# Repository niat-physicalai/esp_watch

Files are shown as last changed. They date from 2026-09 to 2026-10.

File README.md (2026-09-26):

# ESP Watch

A custom ESP32-C3-based wearable device that combines a small OLED display, motion sensing, heart-rate sensing,
Wi-Fi/BLE connectivity, and a LiPo battery into a compact wrist-worn platform.

The project covers the complete product-development workflow — from breadboard prototyping and firmware development
to schematic capture, custom PCB design, fabrication, and enclosure CAD.

## Features

* **Seeed XIAO ESP32-C3**
* **0.96" 128×64 SSD1306 OLED**
* **MPU-6050** 6-axis IMU
* **MAX30102** heart-rate / SpO₂ sensor
* 2 user buttons
* LiPo battery operation
* Wi-Fi / Bluetooth Low Energy
* Custom 2-layer carrier PCB
* 3D-printed enclosure

---

## Hardware

| Component | Details |
| --- | --- |
| MCU | XIAO ESP32-C3 |
| Display | SSD1306 OLED, 128×64 |
| IMU | MPU-6050 |
| Heart-rate sensor | MAX30102 |
| Communication | Wi-Fi + BLE |
| Power | LiPo |
| PCB | Custom 38 × 38 mm, 2-layer |

## System Architecture
                         LiPo Battery
                              │
                       Optional Switch
                              │
                       XIAO BAT+ / BAT-
                              │
                    ┌─────────┴─────────┐
                    │                   │
                 XIAO ESP32-C3       Charger
                    │
                  3.3 V
                    │
          ┌─────────┼──────────┐
          │         │          │
       SSD1306   MPU-6050   MAX30102
       OLED       IMU       HR / SpO₂
       0x3C       0x68         0x57
          │         │          │
          └─────────┴──────────┘
                 I²C Bus
             SDA = GPIO6
             SCL = GPIO7

       GPIO10 ── Next Button
       GPIO3 ── Previous Button

### Pinout

| XIAO Pin | Function |
| --- | --- |
| D4 / GPIO6 | I²C SDA |
| D5 / GPIO7 | I²C SCL |
| D10 / GPIO10 | Next button |
| D1 / GPIO3 | Previous button |

The OLED, MPU-6050 and MAX30102 share the I²C bus. No interrupt pins are used for the MPU-6050 or MAX30102.

### Battery

The reference design currently treats the battery as a placeholder. The documented placeholder is:

Capacity: 400 mAh
Approximate dimensions: 20 × 5 × 13 mm

---

## Breadboard Prototype

The watch electronics were first assembled and tested on a breadboard before moving to the custom PCB.

**Figure 1 — Breadboard prototype**

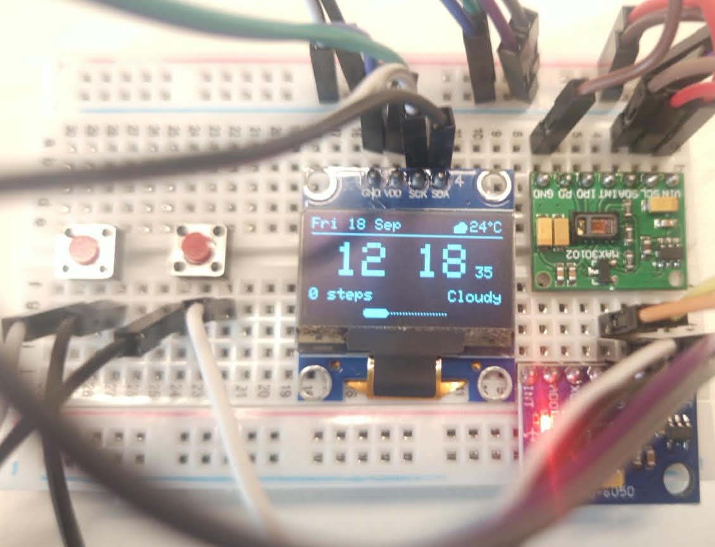
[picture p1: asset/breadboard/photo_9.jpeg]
Breadboard Prototype


*Initial ESP32-C3 smartwatch prototype with the display and sensor modules connected for firmware and hardware testing.*

Additional prototype photos are available in [`asset/breadboard/`](asset/breadboard/).

---

## Circuit Schematic

The final circuit was designed around the XIAO ESP32-C3 with the display and sensors connected through the I²C bus.

**Figure 2 — Circuit schematic**

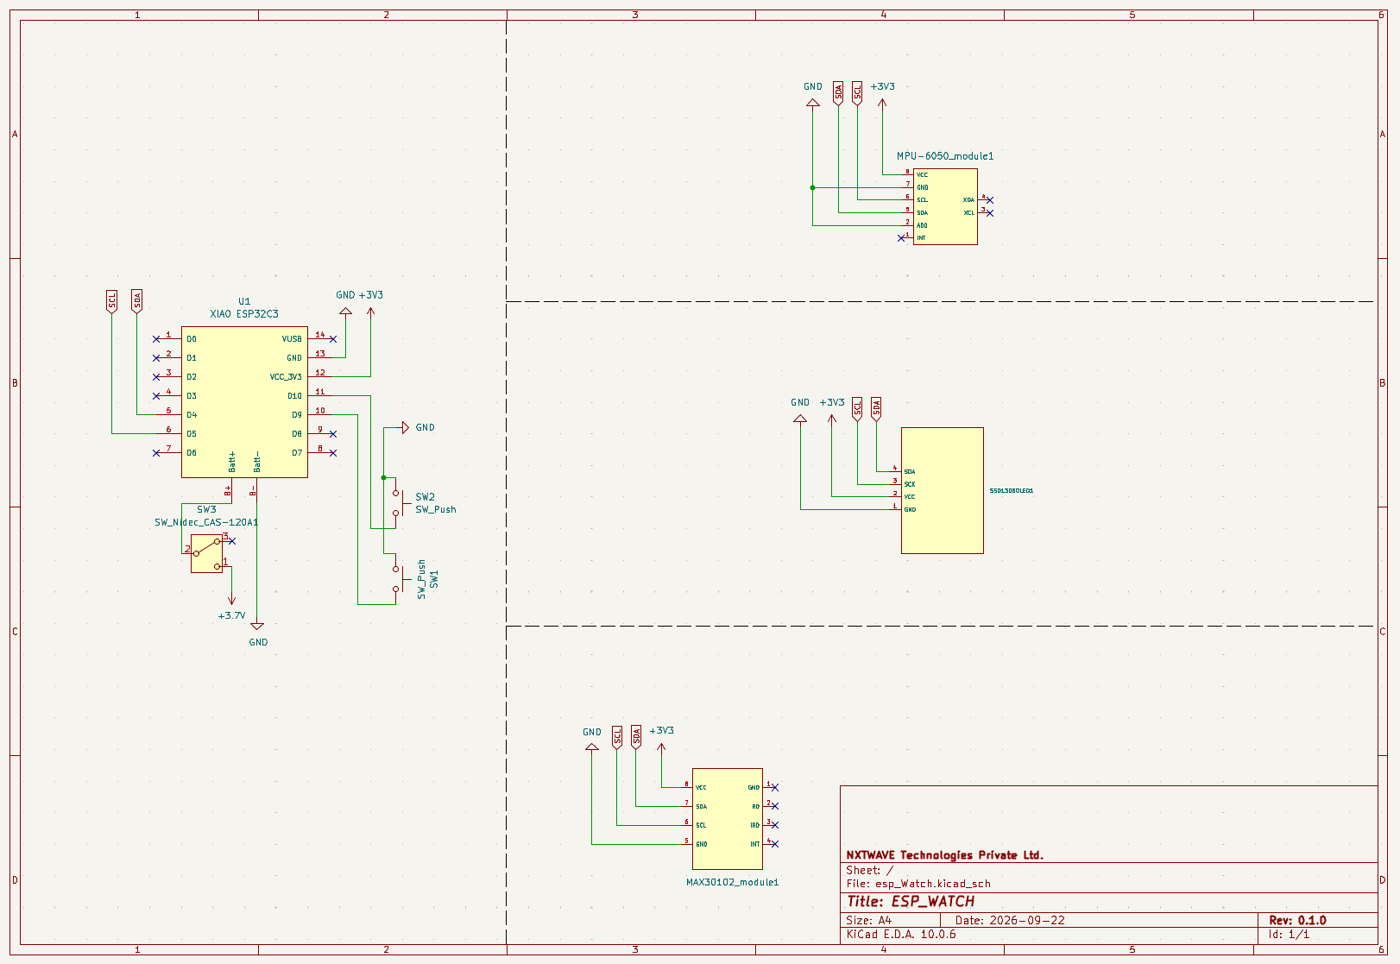
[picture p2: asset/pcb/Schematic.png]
ESP Watch Schematic


*Complete schematic of the ESP Watch carrier board.*

---

## PCB Design

The prototype was converted into a custom 2-layer carrier PCB measuring approximately **38 × 38 mm**.

The custom carrier PCB is:
* 38 × 38 mm
* 2-layer
* Module-based design
* Custom KiCad schematic symbols
* Custom MAX30102 footprint
* Ground pours on both layers
* Hand-assembly oriented

**Figure 3 — PCB top view**

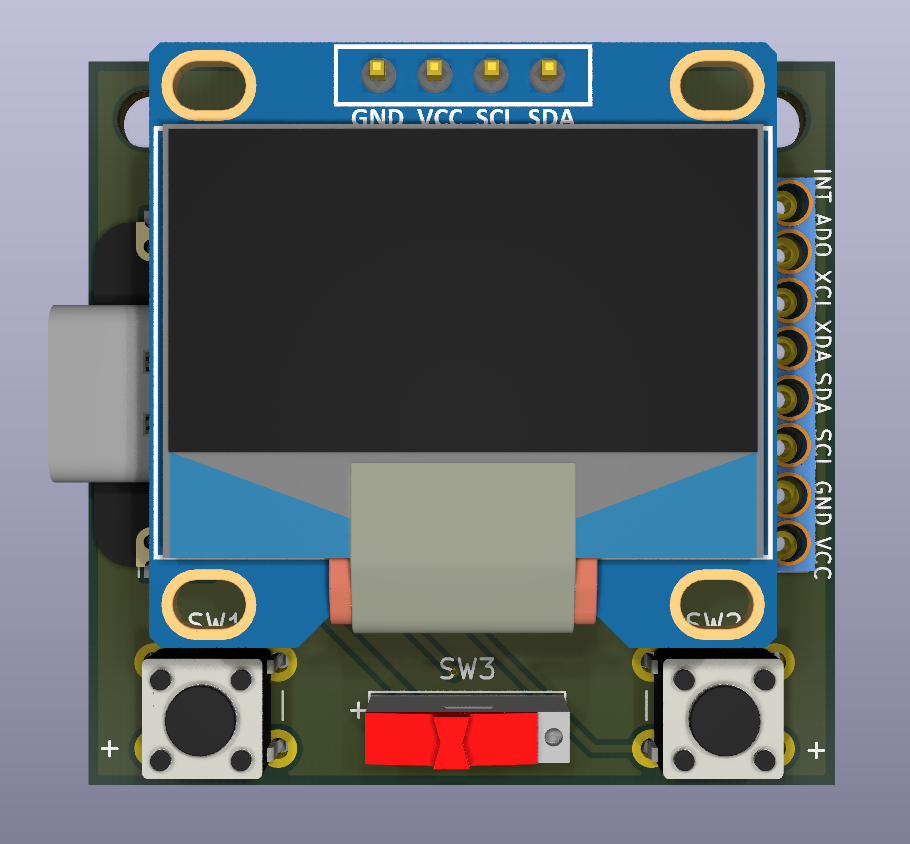
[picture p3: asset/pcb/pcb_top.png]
PCB Top


*Fully rendered top view showing the component placement and routing of the ESP Watch PCB.*

**Figure 4 — PCB front copper**

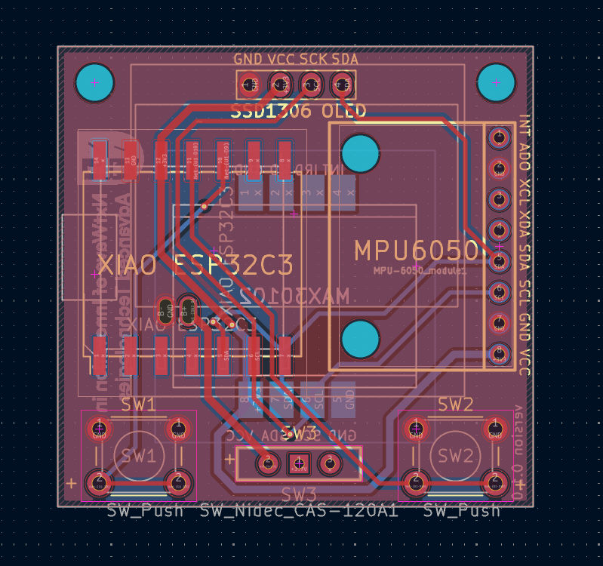
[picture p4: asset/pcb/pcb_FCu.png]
PCB Front Copper


*Front copper layer showing signal and power routing.*

The repository also contains additional PCB views and renders in [`asset/pcb/`](asset/pcb/).

---

## Firmware

Firmware is written in Arduino C++ and can be developed using:

* **Arduino IDE** — `firmware/Arduino-IDE/`
* **PlatformIO** — `firmware/PlatformIO/`

The firmware interfaces with the display and sensors over I²C and handles the watch UI, buttons, motion and heart-rate functionality.

---

## Getting Started
### 1. Clone the repository
```bash
git clone https://github.com/niat-physicalai/esp_watch.git
cd esp_watch
```

### 2. Firmware

Choose one of the supported development environments:

firmware/
├── Arduino-IDE/
└── PlatformIO/

### Arduino IDE

Open:

`firmware/Arduino-IDE/esp_watch/esp_watch.ino`

Select the appropriate ESP32-C3 board configuration and upload the firmware.

### PlatformIO

Open:

`firmware/PlatformIO/esp_watch/`

using VS Code with the PlatformIO extension.

Then build and upload the project.

*Note** Exact board-manager/library versions and firmware configuration requirements should be verified against the current project files before treating them as fixed requirements.

---

## Repository Structure

```text
esp_watch/
├── asset/
│   ├── breadboard/      # Prototype photos
│   └── pcb/             # PCB renders and schematic
│
├── firmware/
│   ├── Arduino-IDE/     # Arduino IDE firmware
│   └── PlatformIO/      # PlatformIO project
│
├── README.md
└── dir.txt
```

---

## Status

* [x] Breadboard prototype
* [x] Firmware
* [x] PCB design
* [ ] PCB fabrication / assembly
* [ ] Enclosure development

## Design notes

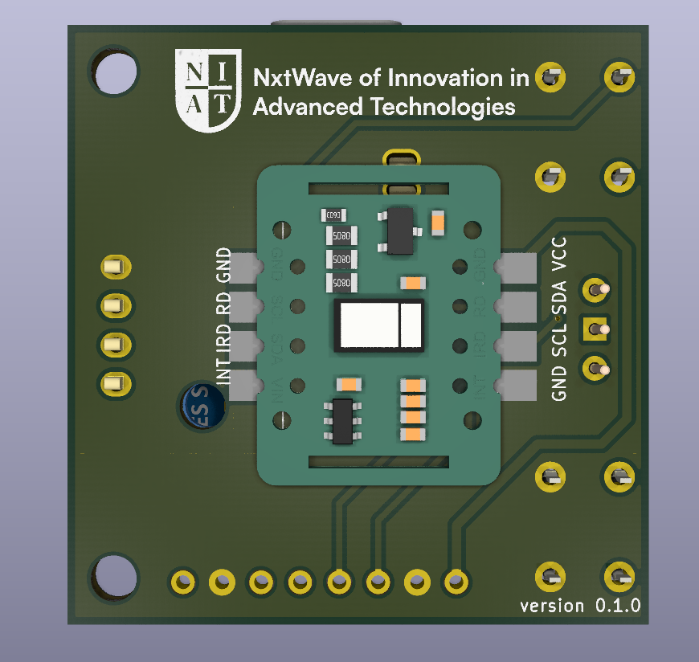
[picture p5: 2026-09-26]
asset/pcb/pcb_back.png

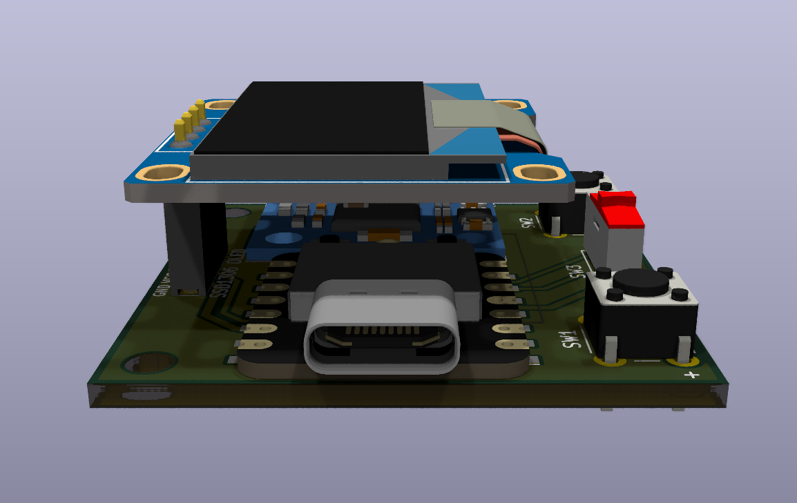
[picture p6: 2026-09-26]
asset/pcb/pcb_side.png

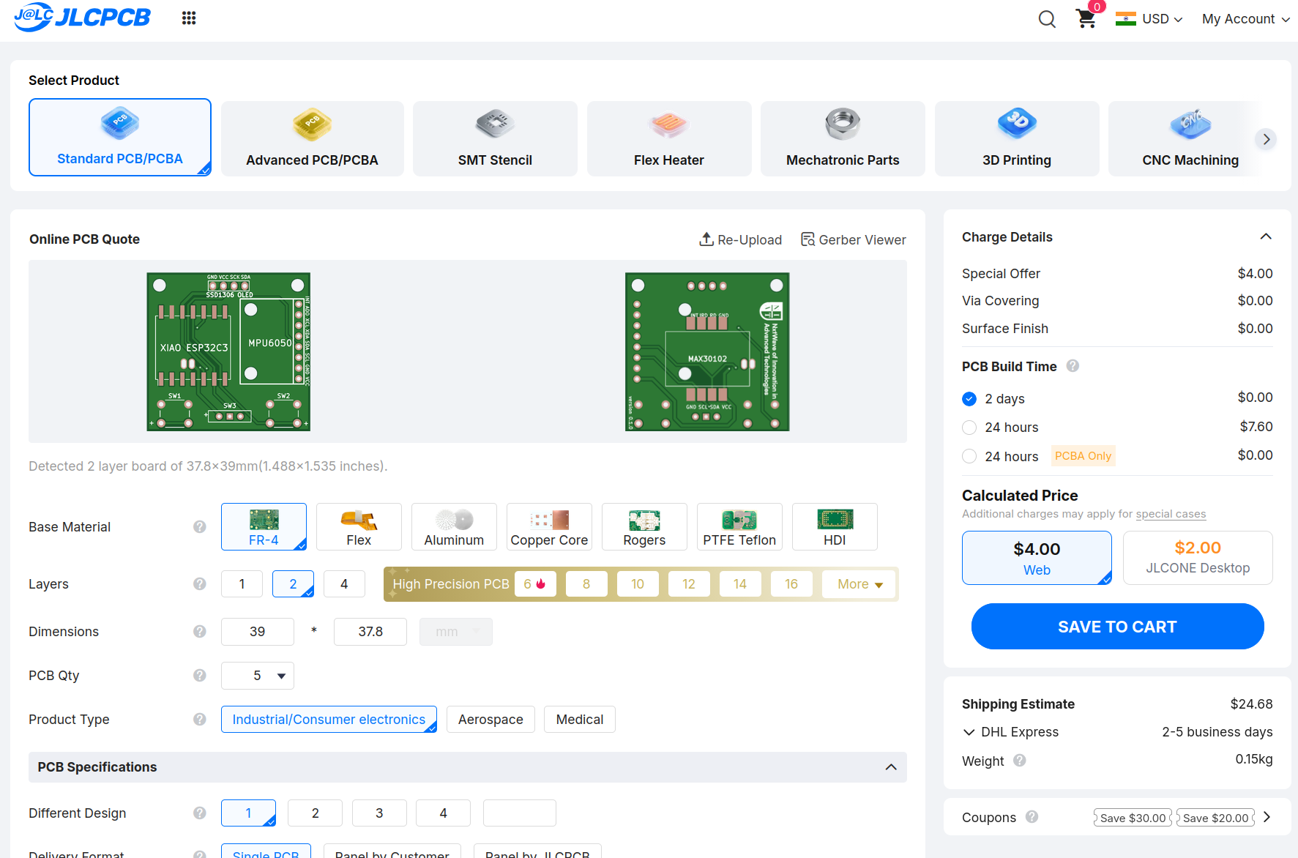
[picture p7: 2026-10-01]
asset/pcb/JLCPCB_quote.png

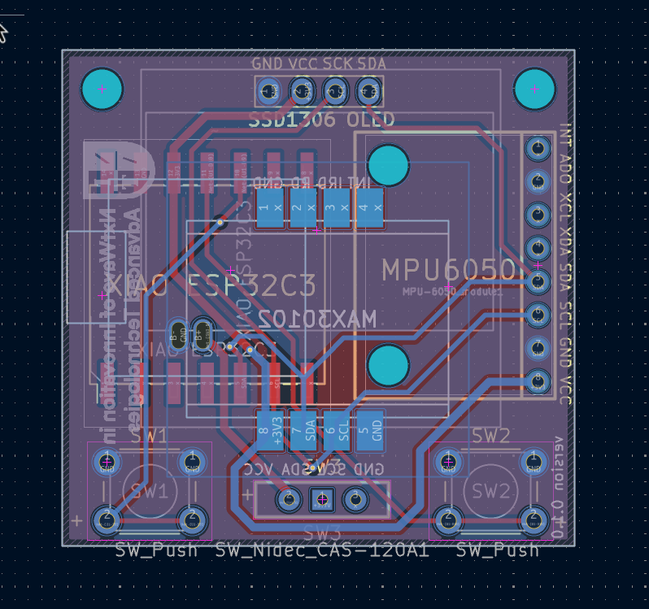
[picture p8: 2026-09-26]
asset/pcb/pcb_BCu.png

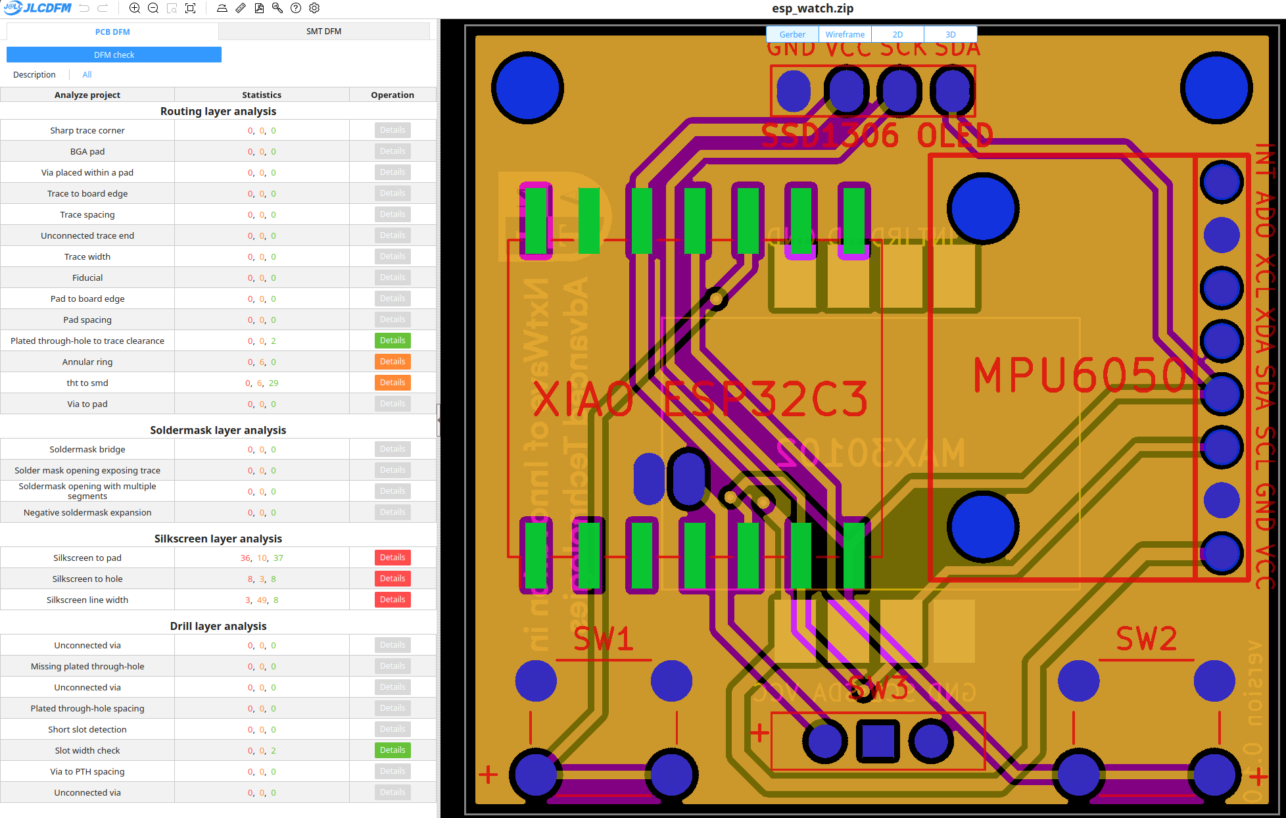
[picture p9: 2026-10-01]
asset/pcb/DFM_check.png

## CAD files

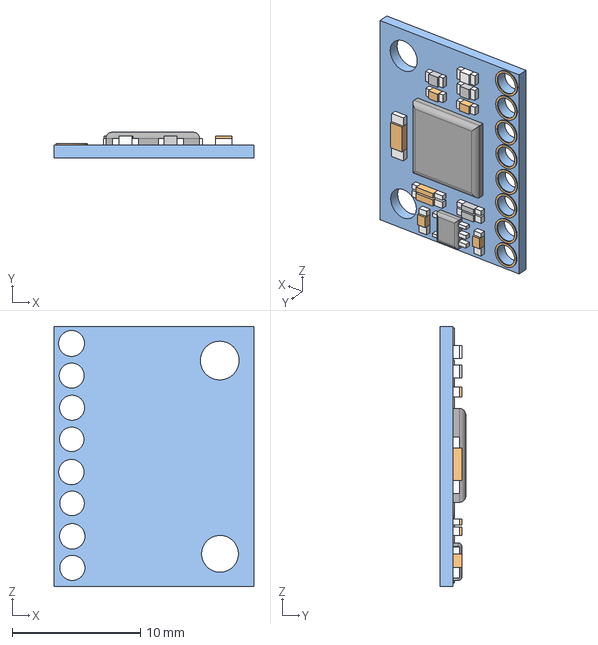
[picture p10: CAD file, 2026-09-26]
pcb/esp_Watch/3d models/MPU6050 v2.step
15.6 x 2.00 x 20.3 mm

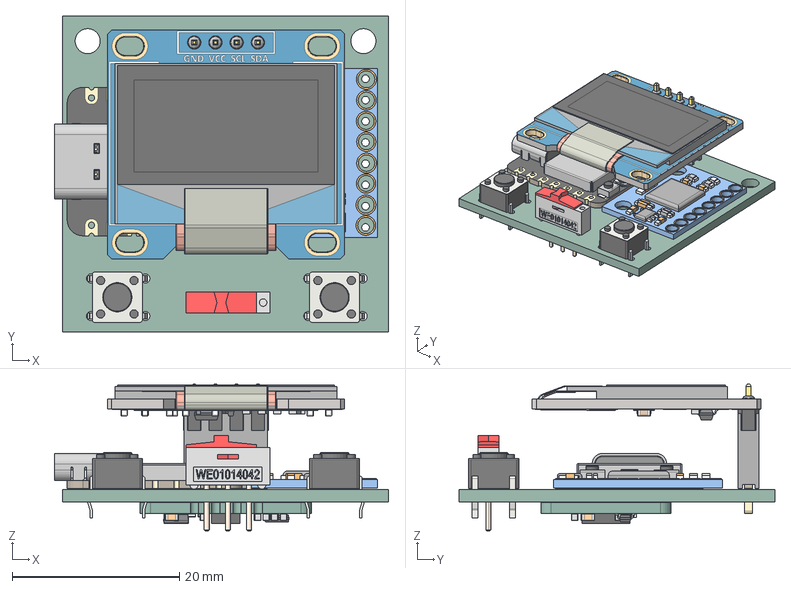
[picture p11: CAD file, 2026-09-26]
pcb/esp_Watch/esp_Watch.step
40.0 x 37.8 x 17.6 mm
662k - XC6206P182MR-G
R SMD 472 x 4
R SMD 914
C SMD 0603 x 8
SOD323F_DIO
Female Pin Header v1
MPU6050 v2
BOSS-EXTRUDE14_8_
BOSS-EXTRUDE7_4_
BOSS-EXTRUDE7_3_
BOSS-EXTRUDE14_4_
BOSS-EXTRUDE14_2_
BOSS-EXTRUDE14_11_
BOSS-EXTRUDE7_7_
BOSS-EXTRUDE14_9_
BOSS-EXTRUDE14_3_
BOSS-EXTRUDE14_7_
MIRROR2
BOSS-EXTRUDE14_5_
BOSS-EXTRUDE14_12_
BOSS-EXTRUDE7_8_
BOSS-EXTRUDE7_1_
BOSS-EXTRUDE14_10_
BOSS-EXTRUDE7_9_
BOSS-EXTRUDE14_6_
BOSS-EXTRUDE14_1_
BOSS-EXTRUDE7_6_
BOSS-EXTRUDE7_2_
CUT-EXTRUDE5
BOSS-EXTRUDE7_5_
U.FL Connector v1
Button (1) x 2
Shield
SW_PUSH_6mm x 2
SOT-23-6 v1
ceramic_cap_0603 v1 x 7
Деталь1 x 4
Деталь2 x 8
SOT23-3 v1
esp_Watch_PCB

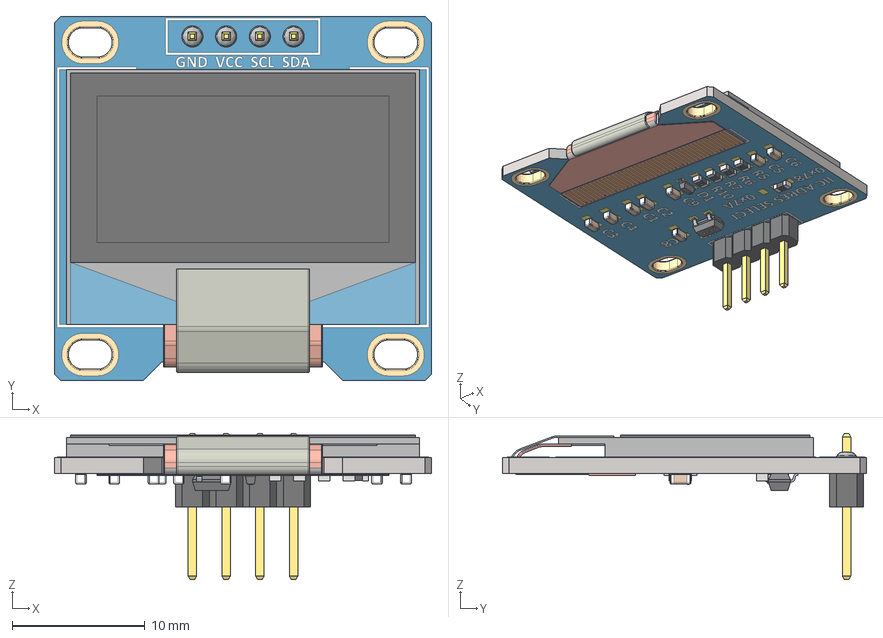
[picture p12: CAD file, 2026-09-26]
pcb/esp_Watch/3d models/Pantalla OLED 0.96'' 128x64.stp
28.4 x 27.4 x 11.0 mm
SOT-23_TOR
RES_CR16_MTK_1 x 4
RES_CR16_MTK
SOD323F_DIO

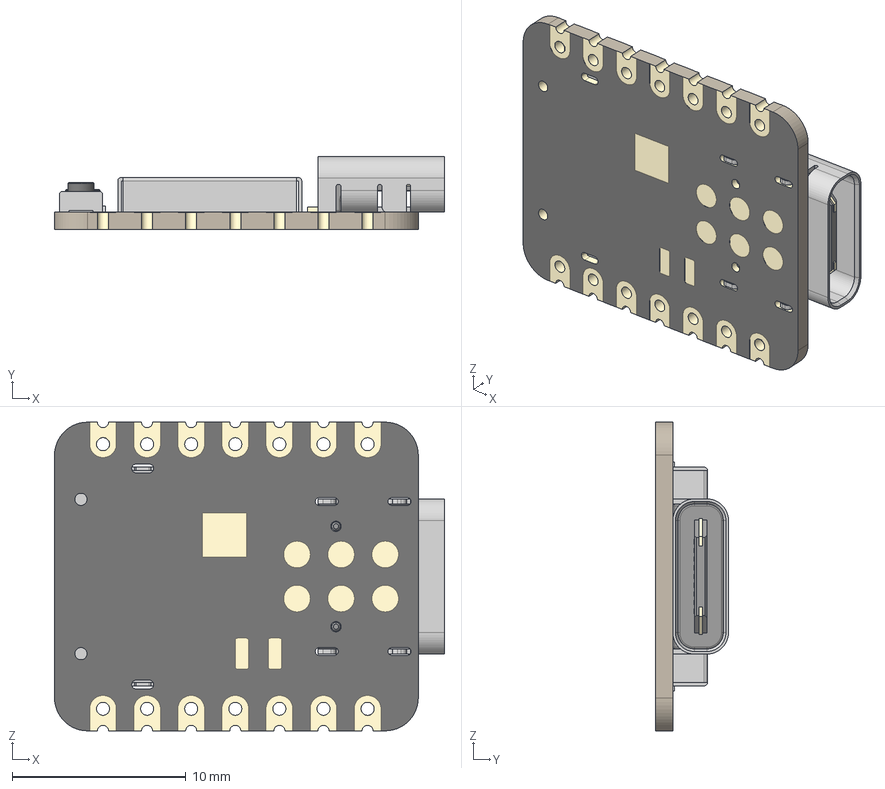
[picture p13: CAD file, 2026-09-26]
pcb/esp_Watch/3d models/Seeed Studio XIAO-ESP32-C3.step
22.5 x 4.21 x 17.8 mm
BOSS-EXTRUDE14_8_
BOSS-EXTRUDE7_4_
BOSS-EXTRUDE7_3_
BOSS-EXTRUDE14_4_
BOSS-EXTRUDE14_2_
BOSS-EXTRUDE14_11_
BOSS-EXTRUDE7_7_
BOSS-EXTRUDE14_9_
BOSS-EXTRUDE14_3_
BOSS-EXTRUDE14_7_
MIRROR2
BOSS-EXTRUDE14_5_
BOSS-EXTRUDE14_12_
BOSS-EXTRUDE7_8_
BOSS-EXTRUDE7_1_
BOSS-EXTRUDE14_10_
BOSS-EXTRUDE7_9_
BOSS-EXTRUDE14_6_
BOSS-EXTRUDE14_1_
BOSS-EXTRUDE7_6_
BOSS-EXTRUDE7_2_
CUT-EXTRUDE5
BOSS-EXTRUDE7_5_
U.FL Connector v1
Button (1) x 2
Shield

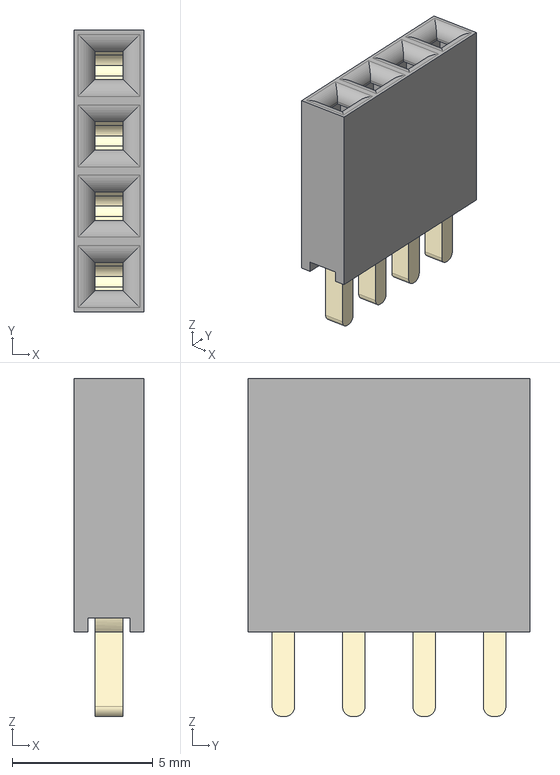
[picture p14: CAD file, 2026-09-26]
pcb/esp_Watch/3d models/Female 4 Pin Header.step
2.50 x 10.0 x 12.0 mm

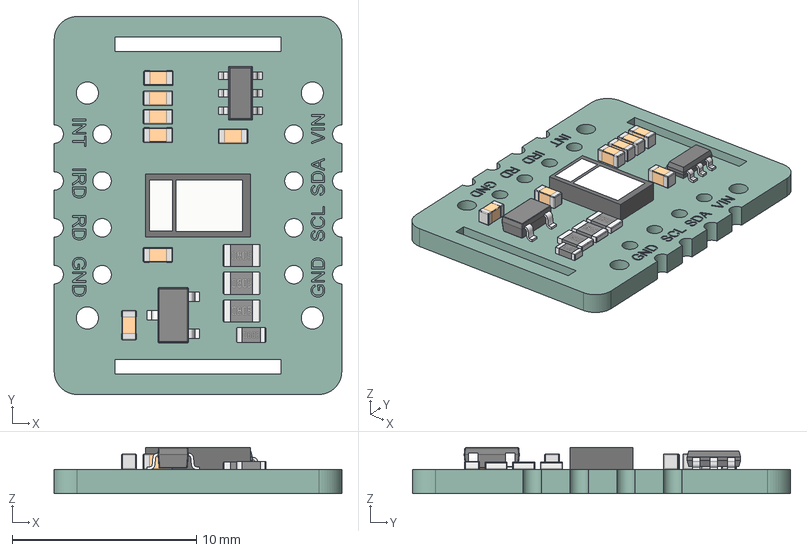
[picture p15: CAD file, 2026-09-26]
pcb/esp_Watch/3d models/MAX30102_MH_ET_LIVE_BOARD_v8.step
15.6 x 20.5 x 2.50 mm
SOT-23-6
ceramic_cap_0603 x 7
Деталь1
Деталь2 x 2
Деталь1_1 x 3
Деталь2_1 x 6
SOT23-3

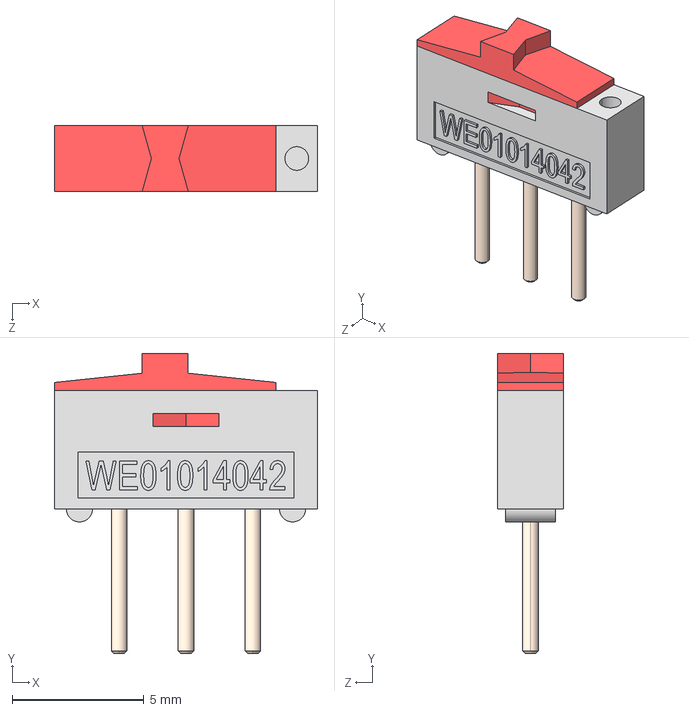
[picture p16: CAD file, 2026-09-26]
pcb/esp_Watch/3d models/450301014042.stp
10.0 x 11.4 x 2.50 mm

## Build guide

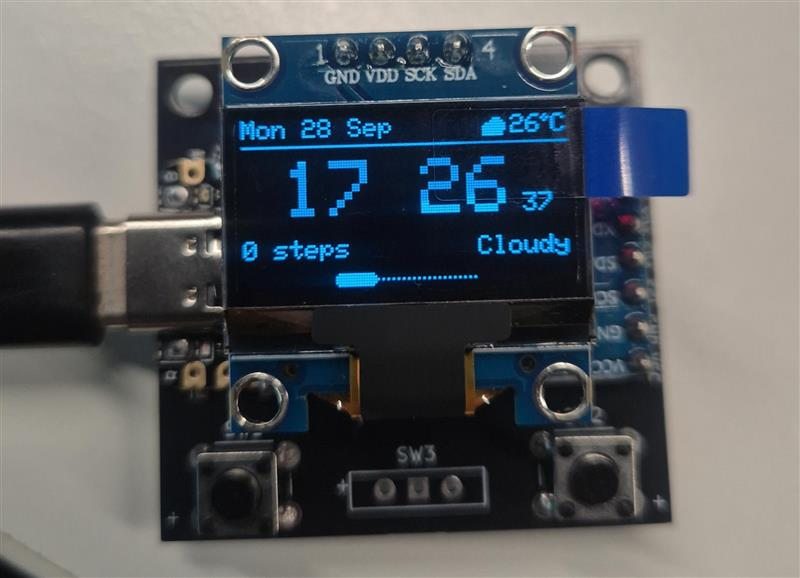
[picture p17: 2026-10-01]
asset/Assembled/Top_assembled.png

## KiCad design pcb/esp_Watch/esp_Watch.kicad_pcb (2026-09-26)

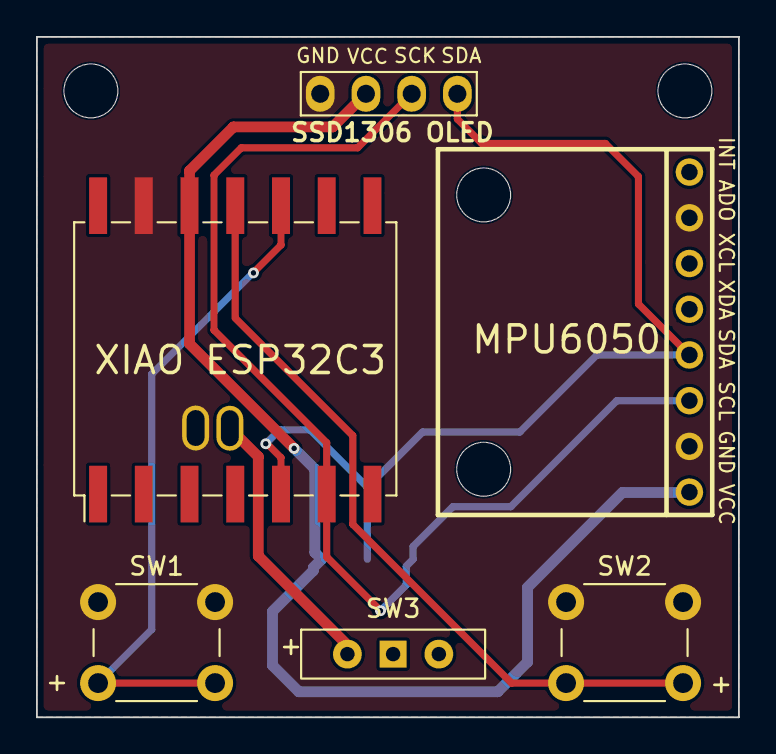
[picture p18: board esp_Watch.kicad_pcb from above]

Board: 2 copper layers, 39.0 x 37.8 mm, 7 parts (1 on the bottom side), 7 nets.

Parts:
MAX30102: MAX30102 module
MPU-6050_module1: GY-521 MPU6050 MODULE FOOTPRINT
SSD1306 OLED: 128x64OLED
SW1, SW2: SW_Push; SW_PUSH_6mm
SW3: SW_Nidec_CAS-120A1; SW_Slide-03_Wuerth-WS-SLTV_10x2.5x6.4_P2.54mm
XIAO ESP32C3: XIAO ESP32C3; xiao_esp32c3

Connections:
+3V3: MAX30102.8 (VCC), MPU-6050_module1.8 (VCC), SSD1306 OLED.2 (VCC), XIAO ESP32C3.12 (VCC_3V3)
GND: MAX30102.5 (GND), MPU-6050_module1.2 (AD0), MPU-6050_module1.7 (GND), SSD1306 OLED.1 (GND), SW1.1, SW2.1, XIAO ESP32C3.13 (GND), XIAO ESP32C3.B- (Batt-)
unnamed: SW3.2 (B), XIAO ESP32C3.B+ (Batt+)
unnamed: SW1.2, XIAO ESP32C3.10 (D9)
unnamed: SW2.2, XIAO ESP32C3.11 (D10)
SCL: MAX30102.6 (SCL), MPU-6050_module1.6 (SCL), SSD1306 OLED.3 (SCK), XIAO ESP32C3.6 (D5)
SDA: MAX30102.7 (SDA), MPU-6050_module1.5 (SDA), SSD1306 OLED.4 (SDA), XIAO ESP32C3.5 (D4)

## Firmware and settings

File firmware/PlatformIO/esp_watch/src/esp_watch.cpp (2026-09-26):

/*
  ESP32 Smartwatch - UI + Sensor Test
  ===================================
  Hardware:
    ESP32 DevKit
    Main I2C bus  (SDA=21, SCL=22): SSD1306 128x64 OLED (0x3C), MPU6050 (0x68)
    MAX I2C bus   (SDA=25, SCL=26): MAX30102/MAX30105 (0x57)
      The MAX gets its own bus because many MAX30102 modules pull SDA/SCL
      up to 1.8V, which corrupts a bus shared with 3.3V devices.
      Set MAX_SEPARATE_BUS to 0 to put it back on the main bus.
    BTN_NEXT -> GPIO32 to GND   (internal pull-up, active LOW)
    BTN_PREV -> GPIO33 to GND   (internal pull-up, active LOW)

  Screens (slide animation + page indicator bar at the bottom):
    0: Clock   - big time, date, weather (Open-Meteo, no API key), steps
    1: Steps   - big steps/goal, animated loading bar, kcal + km
    2: Heart   - pounding heart while waiting/measuring, live pulse wave,
                 then the measured BPM with a heart beating in sync

  Buttons:
    NEXT short  -> next screen          PREV short -> previous screen
    NEXT long   -> context action:
                   Clock: refresh time + weather
                   Steps: reset step count
                   Heart: restart measurement
    PREV long   -> jump to Clock screen
    Any press while the screen is off only wakes it.

  Libraries: Adafruit SSD1306, Adafruit GFX, MPU6050 (i2cdevlib / Electronic Cats),
             SparkFun MAX3010x. WiFi + HTTPClient come with the ESP32 core.
*/

#include <Arduino.h>   // required when built as main.cpp under PlatformIO
#include <Wire.h>
#include <WiFi.h>
#include <HTTPClient.h>
#include <time.h>
#include <Adafruit_GFX.h>
#include <Adafruit_SSD1306.h>
#include <MPU6050.h>
#include "MAX30105.h"
#include "heartRate.h"

// Custom types used as function return values must be declared before the
// first function, because the Arduino IDE auto-inserts function prototypes there.
enum WxType { WX_CLEAR, WX_CLOUD, WX_FOG, WX_DRIZZLE, WX_RAIN, WX_SNOW, WX_STORM };
enum BtnEvent { BTN_NONE, BTN_SHORT, BTN_LONG };

// ======================= USER CONFIG =======================
const char* WIFI_SSID = "Oppo";
const char* WIFI_PASS = "12345678";
const char* TZ_INFO   = "IST-5:30";        // POSIX timezone string
const bool  USE_24H   = true;

// Set these to your location for weather
const float WEATHER_LAT = 0.0f;
const float WEATHER_LON = 0.0f;
const unsigned long WEATHER_REFRESH_MS = 15UL * 60UL * 1000UL;

const uint32_t STEP_GOAL     = 10000;
const float    KCAL_PER_STEP = 0.04f;   // rough average for ~70 kg adult
const float    STRIDE_M      = 0.75f;

// ======================= PINS / TIMING =======================
#define PIN_SDA   21
#define PIN_SCL   22
#define BTN_NEXT  32
#define BTN_PREV  33

// 100 kHz is what worked in sensor_test.ino. At 100 kHz a full OLED frame
// takes ~90 ms, so animations run at ~12 fps. Once the bus is stable
// (short wires, 4.7k pull-ups) you can try 4000o00 for ~30 fps.
#define I2C_CLOCK 100000UL

// Set to 0 to test without WiFi (helps check for power-related glitches)
#define ENABLE_WIFI 1

// MAX30102 on its own I2C bus (ESP32 second I2C controller)
#define MAX_SEPARATE_BUS 0
#define MAX_SDA 25
#define MAX_SCL 26
#if MAX_SEPARATE_BUS
  #define MAX_WIRE Wire1
#else
  #define MAX_WIRE Wire
#endif

#define SCREEN_W  128
#define SCREEN_H  64
#define NUM_SCREENS 3
#define INDICATOR_Y 58            // content must stay above this line

#define FRAME_MS           (I2C_CLOCK >= 400000UL ? 33 : 80)
#define TRANS_MS           260    // screen slide duration
#define LONG_PRESS_MS      800
#define DEBOUNCE_MS        25
#define SCREEN_TIMEOUT_MS  0      // 0 = never sleep (testing). e.g. 15000 for 15 s

// ======================= OBJECTS =======================
// Last two args: I2C clock during and after display transfers
Adafruit_SSD1306 display(SCREEN_W, SCREEN_H, &Wire, -1, I2C_CLOCK, I2C_CLOCK);
MPU6050  mpu(0x68);
MAX30105 maxSensor;

bool oled_ok = false, mpu_ok = false, max_ok = false;
uint32_t busRecoveries = 0;

// ======================= BUTTONS =======================

struct Button {
  uint8_t pin;
  bool stable = HIGH, lastRead = HIGH, longFired = false;
  unsigned long lastChange = 0, pressStart = 0;
  Button(uint8_t p) : pin(p) {}
};

Button btnNext(BTN_NEXT);
Button btnPrev(BTN_PREV);

BtnEvent pollButton(Button& b) {
  bool r = digitalRead(b.pin);
  unsigned long now = millis();
  if (r != b.lastRead) { b.lastRead = r; b.lastChange = now; }

  if (now - b.lastChange < DEBOUNCE_MS || r == b.stable) {
    // No confirmed change: check for long press while held
    if (b.stable == LOW && !b.longFired && now - b.pressStart >= LONG_PRESS_MS) {
      b.longFired = true;
      return BTN_LONG;
    }
    return BTN_NONE;
  }

  b.stable = r;
  if (r == LOW) {                 // pressed
    b.pressStart = now;
    b.longFired = false;
    return BTN_NONE;
  }
  return b.longFired ? BTN_NONE : BTN_SHORT;   // released
}

// ======================= STEP COUNTER =======================
uint32_t stepCount = 0;

const float LPF_ALPHA  = 0.2f;
const int   WINDOW     = 50;       // 1 s at 50 Hz
const float MIN_P2P_G  = 0.15f;
const unsigned long MIN_STEP_MS = 250, MAX_STEP_MS = 2000;
const int   CONFIRM_STEPS = 4;

float filtMag = 1.0f, prevFilt = 1.0f;
float winMin = 10.0f, winMax = -10.0f, threshold = 1.0f, sensitivity = 0.0f;
int   winCount = 0, pendingSteps = 0;
unsigned long lastStepTime = 0;

void updateStepCounter(float ax, float ay, float az) {
  float mag = sqrt(ax * ax + ay * ay + az * az);
  filtMag += LPF_ALPHA * (mag - filtMag);

  if (filtMag < winMin) winMin = filtMag;
  if (filtMag > winMax) winMax = filtMag;
  if (++winCount >= WINDOW) {
    threshold   = (winMax + winMin) / 2.0f;
    sensitivity = winMax - winMin;
    winMin = 10.0f; winMax = -10.0f; winCount = 0;
  }

  if (prevFilt > threshold && filtMag <= threshold && sensitivity > MIN_P2P_G) {
    unsigned long now = millis();
    unsigned long dt = now - lastStepTime;
    if (dt >= MIN_STEP_MS) {
      if (dt <= MAX_STEP_MS) {
        if (pendingSteps >= CONFIRM_STEPS) stepCount++;
        else if (++pendingSteps == CONFIRM_STEPS) stepCount += CONFIRM_STEPS;
      } else {
        pendingSteps = 1;
      }
      lastStepTime = now;
    }
  }
  prevFilt = filtMag;
}

void sampleAccel() {
  int16_t ax, ay, az;
  mpu.getAcceleration(&ax, &ay, &az);
  // Default range +-2g = 16384 LSB/g
  updateStepCounter(ax / 16384.0f, ay / 16384.0f, az / 16384.0f);
}

// ======================= HEART RATE =======================
enum HrState { HR_OFF, HR_WAIT, HR_MEASURING, HR_RESULT };
HrState hrState = HR_OFF;

const long FINGER_THRESHOLD   = 50000;
const unsigned long MEASURE_MIN_MS = 7000;
const int  MEASURE_MIN_BEATS  = 6;
const byte RATE_SIZE          = 8;

byte  rates[RATE_SIZE];
byte  rateSpot = 0, rateCount = 0;
int   beatAvg = 0, lastBpm = 0, validBeats = 0;
bool  firstBeat = true;
unsigned long lastBeat = 0, measureStart = 0;

// Pulse waveform (1 px per sample, ~33 Hz)
#define WAVE_LEN 76
int16_t wave[WAVE_LEN];
int   waveIdx = 0, dsCount = 0;
float irDC = 0;
bool  dcInit = false;

// Heart animation
float realPulse = 0;                 // 1.0 on a detected beat, decays to 0
unsigned long synthStart = 0;        // phase origin for the fake heartbeat

void resetHeartBuffers() {
  rateSpot = rateCount = 0;
  beatAvg = validBeats = 0;
  firstBeat = true;
  realPulse = 0;
  memset(wave, 0, sizeof(wave));
  dcInit = false;
}

void startMeasurement() {
  resetHeartBuffers();
  measureStart = millis();
  lastBeat = millis();
  hrState = HR_MEASURING;
}

void addBeat(int bpm) {
  // Reject outliers once we have a baseline
  if (rateCount >= 3 && abs(bpm - beatAvg) > beatAvg / 4) return;

  rates[rateSpot++] = (byte)bpm;
  rateSpot %= RATE_SIZE;
  if (rateCount < RATE_SIZE) rateCount++;

  int sum = 0;
  for (byte i = 0; i < rateCount; i++) sum += rates[i];
  beatAvg = sum / rateCount;
  validBeats++;
  realPulse = 1.0f;
}

void processIR(long ir) {
  // --- waveform: remove DC, invert (PPG dips on each beat), downsample ---
  if (!dcInit) { irDC = ir; dcInit = true; }
  irDC += (ir - irDC) * 0.02f;
  if (++dsCount >= 3) {
    dsCount = 0;
    long v = -(long)(ir - irDC);
    wave[waveIdx] = (int16_t)constrain(v, -32000L, 32000L);
    waveIdx = (waveIdx + 1) % WAVE_LEN;
  }

  bool finger = ir > FINGER_THRESHOLD;

  switch (hrState) {
    case HR_WAIT:
      if (finger) startMeasurement();
      break;

    case HR_MEASURING:
    case HR_RESULT:
      if (!finger) {
        if (hrState == HR_RESULT && beatAvg > 0) lastBpm = beatAvg;
        hrState = HR_WAIT;
        synthStart = millis();
        return;
      }
      if (checkForBeat(ir)) {
        unsigned long now = millis();
        long delta = now - lastBeat;
        lastBeat = now;
        if (firstBeat) { firstBeat = false; break; }   // no valid interval yet
        int bpm = 60000 / delta;
        if (bpm >= 40 && bpm <= 200) addBeat(bpm);
      }
      if (hrState == HR_MEASURING &&
          millis() - measureStart >= MEASURE_MIN_MS &&
          validBeats >= MEASURE_MIN_BEATS) {
        hrState = HR_RESULT;
        lastBpm = beatAvg;
      }
      break;

    default:
      break;
  }
}

void updateHeartSensor() {
  if (hrState == HR_OFF || !max_ok) return;
  maxSensor.check();                    // non-blocking FIFO read
  while (maxSensor.available()) {
    processIR(maxSensor.getFIFOIR());
    maxSensor.nextSample();
  }
}

float measureProgress() {
  float tp = (millis() - measureStart) / (float)MEASURE_MIN_MS;
  float bp = validBeats / (float)MEASURE_MIN_BEATS;
  return constrain(min(tp, bp), 0.0f, 1.0f);
}

// Heart pulse amount (0..1) used to scale the heart icon
float heartPulseAmount() {
  bool useReal = (hrState == HR_RESULT) || (hrState == HR_MEASURING && validBeats > 0);
  if (useReal) return realPulse;

  // Synthetic "lub-dub" at ~70 bpm while waiting / before first beat
  unsigned long phase = (millis() - synthStart) % 857;
  if (phase < 120) return 1.0f - phase / 120.0f;
  if (phase >= 180 && phase < 280) return 0.6f * (1.0f - (phase - 180) / 100.0f);
  return 0.0f;
}

// ======================= WEATHER / NETWORK =======================
struct Weather {
  bool  valid = false;
  float tempC = 0;
  int   code  = 0;
} weather;

enum NetState { NET_CONNECTING, NET_READY, NET_OFFLINE };
NetState netState = NET_OFFLINE;
unsigned long wifiStart = 0, lastWeatherAttempt = 0, lastWifiRetry = 0;
bool weatherForce = false;


WxType wxType(int c) {
  if (c <= 1)  return WX_CLEAR;
  if (c <= 3)  return WX_CLOUD;
  if (c <= 48) return WX_FOG;
  if (c <= 57) return WX_DRIZZLE;
  if (c <= 67 || (c >= 80 && c <= 82)) return WX_RAIN;
  if (c <= 77 || c == 85 || c == 86)   return WX_SNOW;
  return WX_STORM;
}

const char* wxText(int c) {
  switch (wxType(c)) {
    case WX_CLEAR:   return "Clear";
    case WX_CLOUD:   return "Cloudy";
    case WX_FOG:     return "Fog";
    case WX_DRIZZLE: return "Drizzle";
    case WX_RAIN:    return "Rain";
    case WX_SNOW:    return "Snow";
    default:         return "Storm";
  }
}

void startWiFi() {
  WiFi.mode(WIFI_STA);
  WiFi.setTxPower(WIFI_POWER_8_5dBm);   // smaller current spikes on the 3.3V rail
  WiFi.begin(WIFI_SSID, WIFI_PASS);
  wifiStart = millis();
  netState = NET_CONNECTING;
}

bool fetchWeather() {
  char url[180];
  snprintf(url, sizeof(url),
    "http://api.open-meteo.com/v1/forecast?latitude=%.4f&longitude=%.4f"
    "&current=temperature_2m,weather_code", WEATHER_LAT, WEATHER_LON);

  HTTPClient http;
  http.setConnectTimeout(4000);
  http.setTimeout(4000);
  if (!http.begin(url)) return false;

  int code = http.GET();
  if (code != 200) { http.end(); return false; }
  String body = http.getString();
  http.end();

  // Minimal parsing, no JSON library needed
  int c = body.indexOf("\"current\":{");
  if (c < 0) return false;
  int t = body.indexOf("\"temperature_2m\":", c);
  int w = body.indexOf("\"weather_code\":", c);
  if (t < 0 || w < 0) return false;

  weather.tempC = body.substring(t + 17).toFloat();
  weather.code  = body.substring(w + 15).toInt();
  weather.valid = true;
  Serial.printf("Weather: %.1f C, code %d\n", weather.tempC, weather.code);
  return true;
}

void updateNetwork(bool busy) {
  unsigned long now = millis();

  switch (netState) {
    case NET_CONNECTING:
      if (WiFi.status() == WL_CONNECTED) {
        Serial.printf("WiFi OK: %s\n", WiFi.localIP().toString().c_str());
        configTzTime(TZ_INFO, "pool.ntp.org", "time.google.com");
        netState = NET_READY;
        weatherForce = true;
      } else if (now - wifiStart > 20000) {
        Serial.println("WiFi failed, retrying later");
        WiFi.disconnect(true);
        WiFi.mode(WIFI_OFF);
        netState = NET_OFFLINE;
        lastWifiRetry = now;
      }
      break;

    case NET_READY:
      if (WiFi.status() != WL_CONNECTED) {
        netState = NET_CONNECTING;       // ESP32 auto-reconnects
        wifiStart = now;
        break;
      }
      if (busy) break;                   // don't block during animations
      if (weatherForce ||
          (!weather.valid && now - lastWeatherAttempt > 30000) ||
          (now - lastWeatherAttempt > WEATHER_REFRESH_MS)) {
        weatherForce = false;
        lastWeatherAttempt = now;
        fetchWeather();
      }
      break;

    case NET_OFFLINE:
#if ENABLE_WIFI
      if (now - lastWifiRetry > 5UL * 60UL * 1000UL) startWiFi();
#endif
      break;
  }
}

bool getTimeNow(struct tm& t) {
  time_t now = time(nullptr);
  localtime_r(&now, &t);
  return now > 1700000000;
}

// ======================= UI STATE =======================
int  currentScreen = 0, prevScreen = 0, transDir = 1;
bool transitioning = false;
unsigned long transStart = 0;

float indicatorX = -1;
float shownProgress = 0;             // animated step bar
float frameDt = 0.033f;              // seconds since last frame

bool screenOn = true;
unsigned long lastActivity = 0;

float easeOutCubic(float t) { t = 1.0f - t; return 1.0f - t * t * t; }

// Fraction to move toward a target this frame, independent of frame rate
float approach(float ratePerSec) { return 1.0f - exp(-ratePerSec * frameDt); }

void onScreenEnter(int s) {
  if (s == 1) shownProgress = 0;     // replay the loading animation
  if (s == 2 && max_ok) {
    maxSensor.wakeUp();
    maxSensor.clearFIFO();
    resetHeartBuffers();
    synthStart = millis();
    hrState = HR_WAIT;
  }
}

void onScreenExit(int s) {
  if (s == 2 && max_ok) {
    if (hrState == HR_RESULT && beatAvg > 0) lastBpm = beatAvg;
    hrState = HR_OFF;
    maxSensor.shutDown();            // LEDs off, saves power
  }
}

void goToScreen(int target, int dir) {
  if (target == currentScreen) return;
  onScreenExit(currentScreen);
  prevScreen = currentScreen;
  currentScreen = target;
  onScreenEnter(currentScreen);
  transDir = dir;
  transStart = millis();
  transitioning = true;
}

// ======================= DRAW HELPERS =======================
void printRight(int rightX, int y, const char* s) {
  display.setCursor(rightX - (int)strlen(s) * 6, y);
  display.print(s);
}

void printCentered(int cx, int y, const char* s, int size = 1) {
  display.setTextSize(size);
  display.setCursor(cx - (int)strlen(s) * 6 * size / 2, y);
  display.print(s);
}

void drawCloud(int x, int y) {
  display.fillCircle(x + 3, y + 4, 2, SSD1306_WHITE);
  display.fillCircle(x + 6, y + 3, 3, SSD1306_WHITE);
  display.fillRect(x + 1, y + 4, 8, 3, SSD1306_WHITE);
}

void drawWeatherIcon(int x, int y, int code) {   // ~10x9 px
  switch (wxType(code)) {
    case WX_CLEAR:
      display.fillCircle(x + 4, y + 4, 2, SSD1306_WHITE);
      display.drawPixel(x + 4, y,     SSD1306_WHITE);
      display.drawPixel(x + 4, y + 8, SSD1306_WHITE);
      display.drawPixel(x,     y + 4, SSD1306_WHITE);
      display.drawPixel(x + 8, y + 4, SSD1306_WHITE);
      display.drawPixel(x + 1, y + 1, SSD1306_WHITE);
      display.drawPixel(x + 7, y + 1, SSD1306_WHITE);
      display.drawPixel(x + 1, y + 7, SSD1306_WHITE);
      display.drawPixel(x + 7, y + 7, SSD1306_WHITE);
      break;
    case WX_CLOUD:
      drawCloud(x, y + 1);
      break;
    case WX_FOG:
      display.drawFastHLine(x, y + 2, 9, SSD1306_WHITE);
      display.drawFastHLine(x + 1, y + 4, 8, SSD1306_WHITE);
      display.drawFastHLine(x, y + 6, 9, SSD1306_WHITE);
      break;
    case WX_DRIZZLE:
    case WX_RAIN:
      drawCloud(x, y);
      display.drawPixel(x + 2, y + 8, SSD1306_WHITE);
      display.drawPixel(x + 5, y + 8, SSD1306_WHITE);
      display.drawPixel(x + 8, y + 8, SSD1306_WHITE);
      break;
    case WX_SNOW:
      drawCloud(x, y);
      display.drawPixel(x + 3, y + 8, SSD1306_WHITE);
      display.drawPixel(x + 7, y + 8, SSD1306_WHITE);
      break;
    default:  // storm
      drawCloud(x, y);
      display.drawLine(x + 5, y + 6, x + 4, y + 8, SSD1306_BLACK);
      display.drawLine(x + 5, y + 7, x + 4, y + 9, SSD1306_WHITE);
      break;
  }
}

void drawHeart(int cx, int cy, int r) {
  display.fillCircle(cx - r, cy, r, SSD1306_WHITE);
  display.fillCircle(cx + r, cy, r, SSD1306_WHITE);
  display.fillTriangle(cx - 2 * r, cy, cx + 2 * r, cy,
                       cx, cy + 2 * r + r / 2, SSD1306_WHITE);
}

void drawAnimatedHeart(int cx, int cy) {
  float p = heartPulseAmount();
  int r = 6 + (int)round(2.0f * p);
  drawHeart(cx, cy - r / 2, r);

  // Expanding ripple right after a beat
  if (p > 0.15f && p < 0.85f) {
    int rr = 14 + (int)((1.0f - p) * 8);
    display.drawCircle(cx, cy + 2, rr, SSD1306_WHITE);
  }
}

void drawWave(int x, int y, int w, int h) {
  int16_t mn = 32767, mx = -32768;
  for (int i = 0; i < WAVE_LEN; i++) {
    if (wave[i] < mn) mn = wave[i];
    if (wave[i] > mx) mx = wave[i];
  }
  long range = (long)mx - mn;
  if (range < 20) range = 20;

  int n = min(w, WAVE_LEN);
  int px = 0, py = 0;
  for (int i = 0; i < n; i++) {
    int idx = (waveIdx + WAVE_LEN - n + i) % WAVE_LEN;   // oldest -> newest
    int yy = y + h - 1 - (int)(((long)wave[idx] - mn) * (h - 1) / range);
    int xx = x + i;
    if (i > 0) display.drawLine(px, py, xx, yy, SSD1306_WHITE);
    px = xx; py = yy;
  }
}

// ======================= SCREENS =======================
void drawClockScreen(int ox) {
  struct tm t;
  bool ok = getTimeNow(t);
  char buf[24];

  // --- top row: date + weather ---
  display.setTextSize(1);
  display.setCursor(ox, 0);
  if (ok) {
    strftime(buf, sizeof(buf), "%a %d %b", &t);
    display.print(buf);
  } else {
    display.print(netState == NET_OFFLINE ? "No WiFi" : "Syncing...");
  }

  if (weather.valid) {
    snprintf(buf, sizeof(buf), "%d", (int)round(weather.tempC));
    int nw = strlen(buf) * 6;
    int x = ox + SCREEN_W - (nw + 4 + 6);             // number + degree + "C"
    display.setCursor(x, 0);
    display.print(buf);
    display.drawCircle(x + nw + 1, 1, 1, SSD1306_WHITE);  // degree sign
    display.setCursor(x + nw + 4, 0);
    display.print("C");
    drawWeatherIcon(x - 12, 0, weather.code);
  } else {
    printRight(ox + SCREEN_W, 0, "--");
  }
  display.drawFastHLine(ox, 10, SCREEN_W, SSD1306_WHITE);

  // --- big time with blinking colon ---
  display.setTextSize(3);
  display.setCursor(ox + 16, 16);
  if (ok) {
    int hr = t.tm_hour;
    if (!USE_24H) { hr %= 12; if (hr == 0) hr = 12; }
    snprintf(buf, sizeof(buf), "%02d%c%02d", hr, (t.tm_sec % 2 == 0) ? ':' : ' ', t.tm_min);
  } else {
    strcpy(buf, "--:--");
  }
  display.print(buf);

  display.setTextSize(1);
  if (ok) {
    snprintf(buf, sizeof(buf), "%02d", t.tm_sec);
    display.setCursor(ox + 110, 30);
    display.print(buf);
    if (!USE_24H) {
      display.setCursor(ox + 110, 18);
      display.print(t.tm_hour < 12 ? "AM" : "PM");
    }
  }

  // --- bottom row: steps + weather text ---
  display.setCursor(ox, 46);
  display.printf("%lu steps", (unsigned long)stepCount);
  if (weather.valid) printRight(ox + SCREEN_W, 46, wxText(weather.code));
}
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
void loop() {
  unsigned long now = millis();

  // Sensors
  static unsigned long lastAccel = 0;
  if (mpu_ok && now - lastAccel >= 20) {        // 50 Hz
    lastAccel = now;
    sampleAccel();
  }
  updateHeartSensor();

  // Input + network
  handleInput();
  updateNetwork(transitioning);

  // Keep screen awake while a heart measurement is running
  if (hrState == HR_MEASURING || hrState == HR_RESULT) lastActivity = now;
  if (SCREEN_TIMEOUT_MS > 0 && screenOn && now - lastActivity > SCREEN_TIMEOUT_MS)
    sleepScreen();

  static unsigned long lastBusCheck = 0;
  if (now - lastBusCheck >= 2000) {
    lastBusCheck = now;
    checkBusHealth();
  }

  // Rendering
  static unsigned long lastFrame = 0;
  if (screenOn && oled_ok && now - lastFrame >= FRAME_MS) {
    float dt = (now - lastFrame) / 1000.0f;
    if (dt > 0.2f) dt = 0.2f;
    lastFrame = now;
    frameDt = dt;
    updateAnimations(dt);
    renderFrame();
    updateHeartSensor();                        // drain FIFO after the I2C burst
  }

  // Midnight step reset
  static unsigned long lastDayCheck = 0;
  static int lastDay = -1;
  if (now - lastDayCheck >= 1000) {
    lastDayCheck = now;
    struct tm t;
    if (getTimeNow(t)) {
      if (lastDay != -1 && t.tm_mday != lastDay) stepCount = 0;
      lastDay = t.tm_mday;
    }
  }

  // Serial debug, 1 Hz
  static unsigned long lastDebug = 0;
  if (now - lastDebug >= 1000) {
    lastDebug = now;
    Serial.printf("screen=%d steps=%lu hrState=%d bpm=%d net=%d mag=%.2fg busFix=%lu\n",
                  currentScreen, (unsigned long)stepCount, hrState, beatAvg,
                  netState, filtMag, (unsigned long)busRecoveries);
  }
}

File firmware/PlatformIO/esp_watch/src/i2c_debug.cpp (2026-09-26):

/*
  I2C Bus Diagnostic - ESP32 + MPU6050 + MAX30102 + SSD1306
  =========================================================
  Finds out WHY the MPU disappears when the MAX is connected.

  Wiring: all three modules on SDA=21, SCL=22, 3V3, GND.

  OPTIONAL but very useful (lets the sketch measure the bus voltage
  without a multimeter): run two extra jumper wires
        SDA (21) --> GPIO34
        SCL (22) --> GPIO35
  GPIO34/35 are input-only ADC pins and will not disturb the bus.
  Set MEASURE_LEVELS to 0 if you don't want to add these wires.

  Serial monitor: 115200 baud.

  PlatformIO: copy this file to src/main.cpp (the Arduino.h include below is
  what the Arduino IDE would otherwise add for you).

  What it does:
    1. Measures the idle voltage on SDA and SCL
    2. Scans the bus at 100 kHz and at 400 kHz
    3. Probes each chip by reading its ID register
    4. Hammers each chip with 200 reads and reports the error rate
    5. Repeats every 4 s, so you can plug/unplug modules and watch live
*/

#include <Arduino.h>     // required when built as main.cpp under PlatformIO
#include <Wire.h>

#define PIN_SDA 21
#define PIN_SCL 22

#define MEASURE_LEVELS 1     // set 0 if you skip the GPIO34/35 jumpers
#define ADC_SDA 34
#define ADC_SCL 35

#define ADDR_OLED 0x3C
#define ADDR_MAX  0x57
#define ADDR_MPU  0x68
#define ADDR_MPU2 0x69       // MPU with AD0 pulled high

#define WIGGLE_TEST 1        // 1 = run the live wire-wiggle test each round

uint32_t busClock = 100000;

// ---------- low-level helpers ----------
bool busAlive = false;      // true once any device has answered

bool ping(uint8_t addr) {
  Wire.beginTransmission(addr);
  return Wire.endTransmission() == 0;
}

// Read n bytes. repeatedStart=false sends a STOP between the write and the
// read, which is what the MPU6050 / SSD1306 libraries actually do.
bool readRegs(uint8_t addr, uint8_t reg, uint8_t* out, uint8_t n, bool repeatedStart) {
  Wire.beginTransmission(addr);
  Wire.write(reg);
  if (Wire.endTransmission(!repeatedStart) != 0) return false;
  if (Wire.requestFrom((int)addr, (int)n) != n) return false;
  for (uint8_t i = 0; i < n; i++) out[i] = Wire.read();
  return true;
}

// Returns true on success, value in *out
bool readReg(uint8_t addr, uint8_t reg, uint8_t* out) {
  Wire.beginTransmission(addr);
  Wire.write(reg);
  if (Wire.endTransmission(false) != 0) return false;    // repeated start
  if (Wire.requestFrom((int)addr, 1) != 1) return false;
  *out = Wire.read();
  return true;
}

bool writeReg(uint8_t addr, uint8_t reg, uint8_t val) {
  Wire.beginTransmission(addr);
  Wire.write(reg);
  Wire.write(val);
  return Wire.endTransmission() == 0;
}

// ---------- 1. bus voltage ----------
void checkLevels() {
#if MEASURE_LEVELS
  // Let the bus idle high, then measure
  delay(5);
  int sda = analogReadMilliVolts(ADC_SDA);
  int scl = analogReadMilliVolts(ADC_SCL);
  Serial.printf("  Idle bus voltage : SDA %d mV | SCL %d mV\n", sda, scl);
  int lo = min(sda, scl);
  if (lo < 500 && busAlive) {
    Serial.println("  (Those readings are meaningless - GPIO34/35 are not");
    Serial.println("   wired to the bus, so they float near 0 V. Devices are");
    Serial.println("   answering normally, so the real bus level is fine.)");
  } else if (lo < 2600) {
    Serial.println("  >> PROBLEM: idle level is well below 3.3 V.");
    Serial.println("     Something is pulling the bus toward a lower rail.");
    Serial.println("     The usual cause is the MAX30102 module: its pull-up");
    Serial.println("     resistors go to its internal 1.8 V rail, not 3.3 V.");
  } else if (lo < 3000) {
    Serial.println("  >> MARGINAL: idle level is low. Expect random failures.");
  } else {
    Serial.println("  Levels look healthy (>3.0 V).");
  }
#else
  // Crude fallback: read the pins as digital inputs
  pinMode(PIN_SDA, INPUT);
  pinMode(PIN_SCL, INPUT);
  delayMicroseconds(200);
  int sda = digitalRead(PIN_SDA), scl = digitalRead(PIN_SCL);
  Serial.printf("  Idle digital level: SDA %s | SCL %s\n",
                sda ? "HIGH" : "LOW", scl ? "HIGH" : "LOW");
  if (!sda || !scl)
    Serial.println("  >> PROBLEM: a line reads LOW while idle. Either a device "
                   "is holding it down, or the pull-up voltage is too low for "
                   "the ESP32 to see as HIGH (needs ~2.5 V).");
  Wire.begin(PIN_SDA, PIN_SCL);
  Wire.setClock(busClock);
#endif
}

// ---------- 2. scan ----------
int scan(uint32_t clk) {
  Wire.setClock(clk);
  Serial.printf("  Scan @ %lu kHz: ", (unsigned long)(clk / 1000));
  int n = 0;
  for (uint8_t a = 1; a < 127; a++) {
    if (ping(a)) {
      Serial.printf("0x%02X ", a);
      n++;
    }
  }
  if (!n) Serial.print("(nothing)");
  Serial.println();
  Wire.setClock(busClock);
  return n;
}

// ---------- 3. identify chips ----------
void identify() {
  uint8_t v;

  // --- MPU6050: WHO_AM_I = 0x75, usually 0x68 (clones return 0x70, 0x72, 0x98) ---
  uint8_t mpuAddr = 0;
  if (ping(ADDR_MPU))       mpuAddr = ADDR_MPU;
  else if (ping(ADDR_MPU2)) mpuAddr = ADDR_MPU2;

  if (!mpuAddr) {
    Serial.println("  MPU6050  : NOT FOUND at 0x68 or 0x69");
  } else {
    Serial.printf("  MPU6050  : responds at 0x%02X", mpuAddr);
    if (readReg(mpuAddr, 0x75, &v)) Serial.printf(", WHO_AM_I = 0x%02X", v);
    else                            Serial.print(", but register read FAILED");
    // Wake it and read one accel byte to prove data flows
    writeReg(mpuAddr, 0x6B, 0x00);
    if (readReg(mpuAddr, 0x3B, &v)) Serial.printf(", accel_xh = 0x%02X", v);
    Serial.println();
    if (mpuAddr == ADDR_MPU2)
      Serial.println("     >> AD0 is HIGH. Tie the MPU's AD0 pin to GND for 0x68.");
  }

  // --- MAX30102: PART_ID register 0xFF should read 0x15 ---
  if (!ping(ADDR_MAX)) {
    Serial.println("  MAX30102 : NOT FOUND at 0x57");
  } else {
    Serial.print("  MAX30102 : responds at 0x57");
    if (readReg(ADDR_MAX, 0xFF, &v)) {
      Serial.printf(", PART_ID = 0x%02X %s", v, (v == 0x15) ? "(correct)" : "(WRONG - bad read)");
    } else {
      Serial.print(", but register read FAILED");
    }
    Serial.println();
  }

  // --- OLED: only ACKs, has no readable ID ---
  Serial.printf("  SSD1306  : %s at 0x3C%s\n",
                ping(ADDR_OLED) ? "responds" : "NOT FOUND",
                ping(ADDR_OLED) ? " (write-only: ACK does not prove clean data)" : "");
}
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

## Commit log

2026-09-18 Added images for breadboard prototype
2026-09-26 Added esp_watch kicad project files
    [450301014042.stp, Female 4 Pin Header.step, MAX30102_MH_ET_LIVE_BOARD_v8.step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]
2026-09-26 Added pcb, schematic images
2026-10-01 Added Gerber for fabrication
2026-10-01 Added top photo of assembled pcb
